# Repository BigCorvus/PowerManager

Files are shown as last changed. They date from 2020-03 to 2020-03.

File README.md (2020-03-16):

# PowerManager
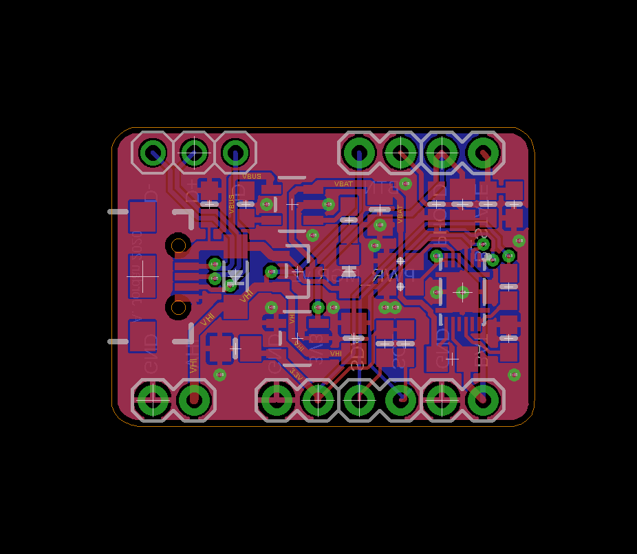
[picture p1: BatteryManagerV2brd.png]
PowerManagerV2

Small battery and power manager PCB based on a previously designed charger+LDO board. Even breaks out the USB data pins and can therefore be integrated into any battery-powered project. Besides the ever-useful sot-23 Lithium charger (MCP73831) and 3,3V LDO this new version has additional features: MCU-controlled power latching using a pushbutton and a BQ27441-G1A fuel gauge with current sensing capability. Various LDO models can be used depending on current requirements and quiescent current. They should match the footprint and have an active high enable pin. Examples are AP2112 or XC6215...  
The BTN_TO_MCU pin is an output which is high as soon as long as the button is pressed. It can beused to control stuff inside your application code. The PHOLD pin is an input which has to be pulled up by the microcontroller as soon as possible. Actually this should be the first thing your code does. After the button is pushed the EN pin of the LDO is pulled up for a short period, which depends on the capacitor. 10µF give you about 2 seconds to react.

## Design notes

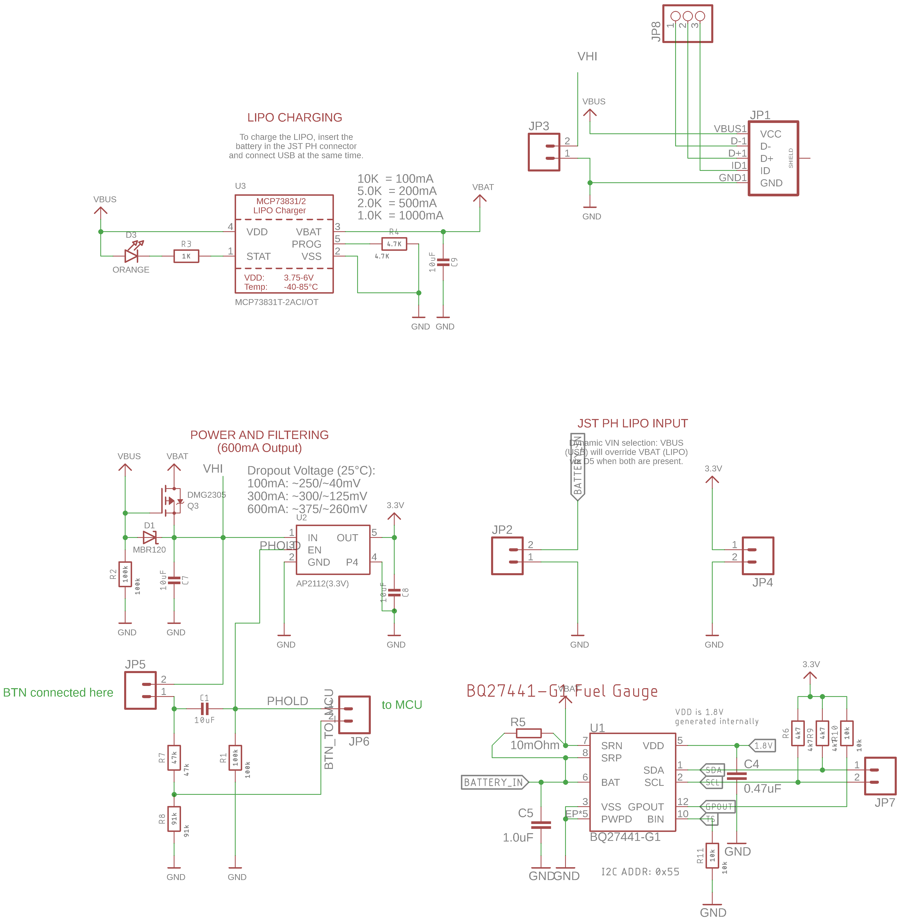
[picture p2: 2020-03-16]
BatteryManagerV2.png

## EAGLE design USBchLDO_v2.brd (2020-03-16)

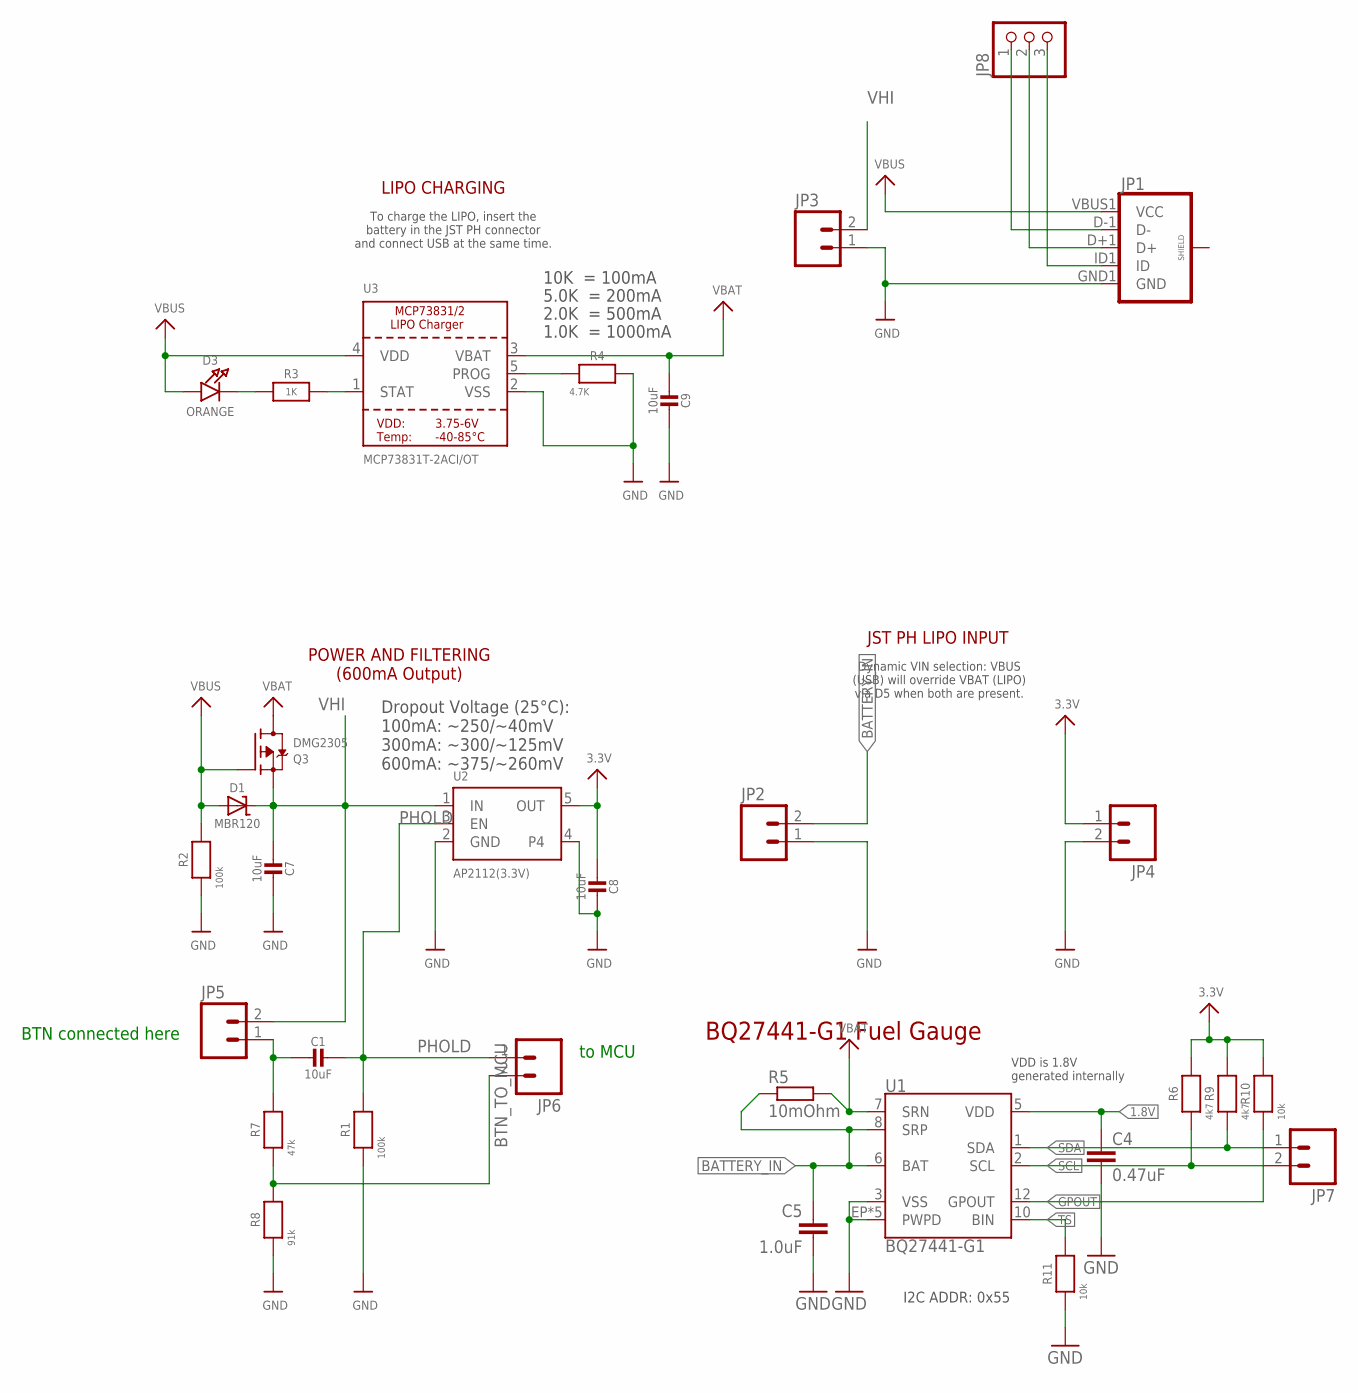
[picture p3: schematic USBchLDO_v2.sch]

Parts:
C1, C7, C8, C9: 10uF; 0805-NO
C4: 0.47uF; 0603-CAP
C5: 1.0uF; 0603-CAP
D1: MBR120; SOD-123
D3: ORANGE; CHIPLED_0805_NOOUTLINE
JP1: USB_MICROB_PLUGCONN-11752; USB-B-MICRO-SMD_V03
JP2, JP3, JP4, JP5, JP6, JP7: M02PTH; 1X02
JP8: PINHD-1X3; 1X03
Q3: DMG2305; SOT23-R
R1, R2: 100k; 0603-NO
R3: 1K; 0603-NO
R4: 4.7K; 0603-NO
R5: 10mOhm; R0805
R6, R9: 4k7; 0603-NO
R7: 47k; 0603-NO
R8: 91k; 0603-NO
R10, R11: 10k; 0603-NO
U1: BQ27441-G1; PDSO-N12
U2: AP2112(3.3V); SOT23-5
U3: MCP73831T-2ACI/OT; SOT23-5

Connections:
1.8V: C4.1, U1.5 (VDD)
3.3V: C8.2, JP4.1, R6.2, R9.2, R10.2, U2.5 (OUT)
BATTERY_IN: C5.1, JP2.2, R5.1, U1.6 (BAT), U1.8 (SRP)
BTN_TO_MCU: JP6.2, R7.1, R8.2
B_IN: C1.2, JP5.1, R7.2
GND: C4.2, C5.2, C7.1, C8.1, C9.1, JP1.GND1 (GND), JP2.1, JP3.1, JP4.2, R1.1, R2.1, R4.2, R8.1, R11.1, U1.3 (VSS), U1.EP (PWPD), U1.EP1 (PWPD), U1.EP2 (PWPD), U1.EP3 (PWPD), U1.EP4 (PWPD), U2.2 (GND), U2.4, U3.2 (VSS)
GPOUT: R10.1, U1.12 (GPOUT)
unnamed: D3.C, R3.1
unnamed: JP1.ID1 (ID), JP8.3
unnamed: R3.2, U3.1 (STAT)
unnamed: R4.1, U3.5 (PROG)
PHOLD: C1.1, JP6.1, R1.2, U2.3 (EN)
SCL: JP7.2, R6.1, U1.2 (SCL)
SDA: JP7.1, R9.1, U1.1 (SDA)
TS: R11.2, U1.10 (BIN)
USB_N: JP1.D-1 (D-), JP8.1
USB_P: JP1.D+1 (D+), JP8.2
VBAT: C9.2, Q3.3 (D), R5.2, U1.7 (SRN), U3.3 (VBAT)
VBUS: D1.A, D3.A, JP1.VBUS1 (VCC), Q3.1 (G), R2.2, U3.4 (VDD)
VHI: C7.2, D1.C, JP3.2, JP5.2, Q3.2 (S), U2.1 (IN)

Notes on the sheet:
POWER AND FILTERING (600mA Output)
Dropout Voltage (25°C): 100mA: ~250/~40mV 300mA: ~300/~125mV 600mA: ~375/~260mV
10K = 100mA
5.0K = 200mA
2.0K = 500mA
1.0K = 1000mA
LIPO CHARGING
To charge the LIPO, insert the battery in the JST PH connector and connect USB at the same time.
JST PH LIPO INPUT
Dynamic VIN selection: VBUS (USB) will override VBAT (LIPO) via D5 when both are present.
BQ27441-G1 Fuel Gauge
VDD is 1.8V generated internally
I2C ADDR: 0x55
to MCU
BTN connected here

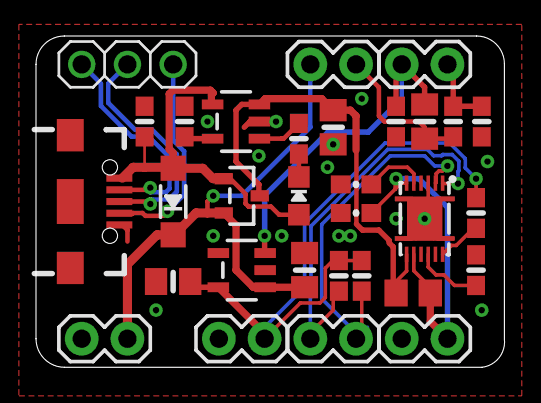
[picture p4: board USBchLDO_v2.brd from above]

Board: 2 copper layers, 26.0 x 18.4 mm, 31 parts (0 on the bottom side), 20 nets.

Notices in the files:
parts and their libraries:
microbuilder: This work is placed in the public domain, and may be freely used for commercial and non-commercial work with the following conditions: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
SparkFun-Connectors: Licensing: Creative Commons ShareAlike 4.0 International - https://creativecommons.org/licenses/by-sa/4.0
